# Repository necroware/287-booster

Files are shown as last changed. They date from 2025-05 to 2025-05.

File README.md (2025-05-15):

# 287 Booster

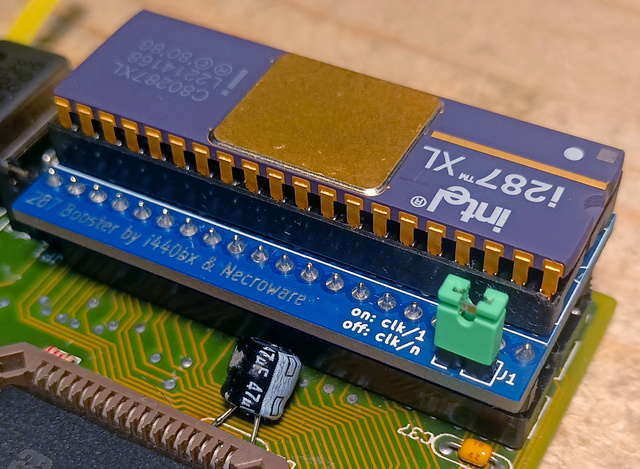
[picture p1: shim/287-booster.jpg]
287 booster


This is an interposer which adds a jumper which can be used to select the clock
divider on a 287 floating point unit. It was designed and open sourced in
cooperation with the user i440bx from the German dosreloaded.de community.

## Background

Intel 287 co-processors have configuration pin 39 for the clock mode signal
(CKM) setup. When this pin is pulled up the chip will use the clock directly. If
it is pulled to ground the chip will use a clock divider. The pin has internal
pull-down resistor, so it can be left unconnected, which will default the
setting to divided clock. Which divider will be used depends on the chip:

- Intel D80287, M80287 run at 1/3 of the clock
- Intel i287XL runs at 1/2 of the clock
- AMD D80C287 runs at 1/3 of the clock

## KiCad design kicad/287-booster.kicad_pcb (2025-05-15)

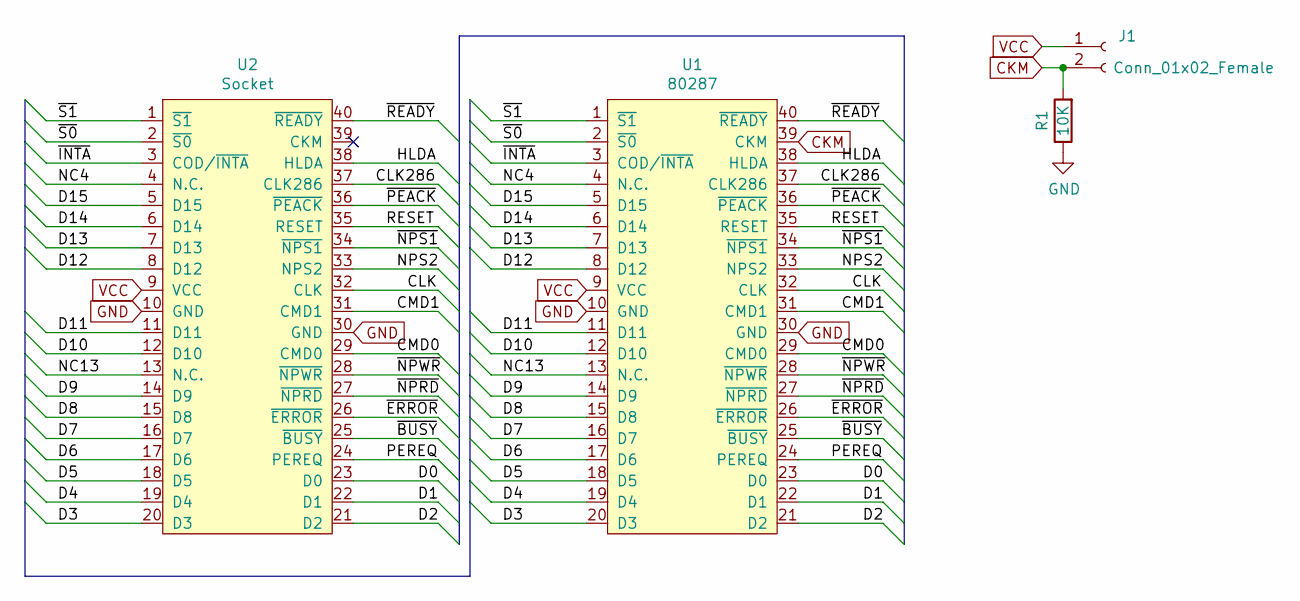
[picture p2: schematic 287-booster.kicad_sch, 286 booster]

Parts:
J1: Conn_01x02_Female; PinHeader_1x02_P2.54mm_Vertical
R1: 10K; R_Axial_DIN0207_L6.3mm_D2.5mm_P7.62mm_Horizontal
U1: 80287; DIP-40_W15.24mm_Socket
U2: Socket; DIP-40_W15.24mm

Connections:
/CLK: U1.32 (CLK), U2.32 (CLK)
/CLK286: U1.37 (CLK286), U2.37 (CLK286)
/CMD0: U1.29 (CMD0), U2.29 (CMD0)
/CMD1: U1.31 (CMD1), U2.31 (CMD1)
/D0: U1.23 (D0), U2.23 (D0)
/D1: U1.22 (D1), U2.22 (D1)
/D2: U1.21 (D2), U2.21 (D2)
/D3: U1.20 (D3), U2.20 (D3)
/D4: U1.19 (D4), U2.19 (D4)
/D5: U1.18 (D5), U2.18 (D5)
/D6: U1.17 (D6), U2.17 (D6)
/D7: U1.16 (D7), U2.16 (D7)
/D8: U1.15 (D8), U2.15 (D8)
/D9: U1.14 (D9), U2.14 (D9)
/D10: U1.12 (D10), U2.12 (D10)
/D11: U1.11 (D11), U2.11 (D11)
/D12: U1.8 (D12), U2.8 (D12)
/D13: U1.7 (D13), U2.7 (D13)
/D14: U1.6 (D14), U2.6 (D14)
/D15: U1.5 (D15), U2.5 (D15)
/HLDA: U1.38 (HLDA), U2.38 (HLDA)
/NC4: U1.4 (N.C.), U2.4 (N.C.)
/NC13: U1.13 (N.C.), U2.13 (N.C.)
/NPS2: U1.33 (NPS2), U2.33 (NPS2)
/PEREQ: U1.24 (PEREQ), U2.24 (PEREQ)
/RESET: U1.35 (RESET), U2.35 (RESET)
/~BUSY: U1.25 (~BUSY), U2.25 (~BUSY)
/~ERROR: U1.26 (~ERROR), U2.26 (~ERROR)
/~INTA: U1.3 (COD/~INTA), U2.3 (COD/~INTA)
/~NPRD: U1.27 (~NPRD), U2.27 (~NPRD)
/~NPS1: U1.34 (~NPS1), U2.34 (~NPS1)
/~NPWR: U1.28 (~NPWR), U2.28 (~NPWR)
/~PEACK: U1.36 (~PEACK), U2.36 (~PEACK)
/~READY: U1.40 (~READY), U2.40 (~READY)
/~S0: U1.2 (~S0), U2.2 (~S0)
/~S1: U1.1 (~S1), U2.1 (~S1)
CKM: J1.2, R1.2, U1.39 (CKM)
GND: R1.1, U1.10 (GND), U1.30 (GND), U2.10 (GND), U2.30 (GND)
VCC: J1.1, U1.9 (VCC), U2.9 (VCC)

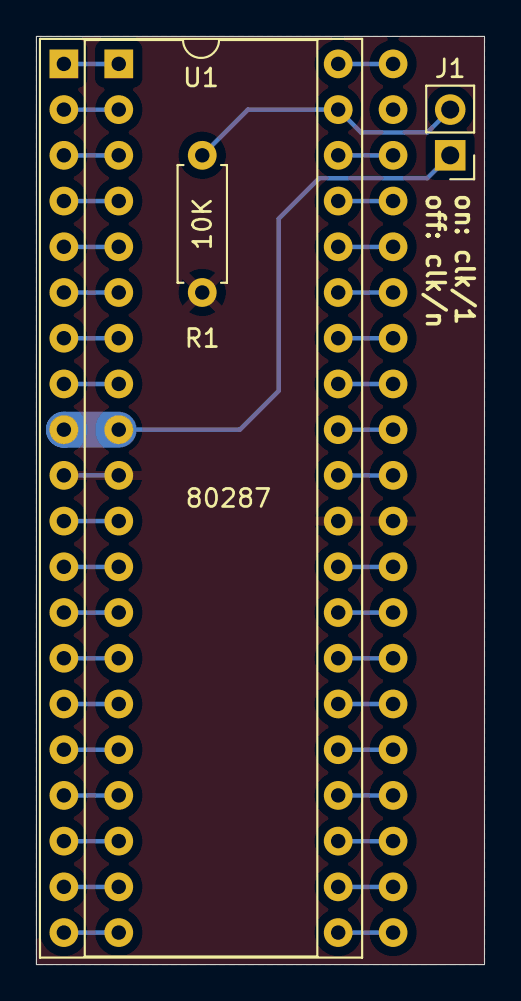
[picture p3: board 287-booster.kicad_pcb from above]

Board: 2 copper layers, 24.9 x 51.6 mm, 4 parts (0 on the bottom side), 39 nets.

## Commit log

2023-02-27 Switched to KiCad 7
    [287-booster.kicad_pcb, 287-booster.kicad_sch, 287-booster.sch]
2024-05-06 Updated project to KiCad 8
    [287-booster.kicad_pcb, 287-booster.kicad_sch]
2025-05-03 Update to KiCad 9
    [287-booster.kicad_pcb, 287-booster.kicad_sch]
2025-05-15 rotated text
    [287-booster.kicad_pcb]
2025-05-15 ignore gerber folder
